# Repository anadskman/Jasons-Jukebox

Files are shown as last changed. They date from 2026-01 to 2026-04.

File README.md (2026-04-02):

# Jasons-Jukebox

jasonsjukebox

A minecraft style jukebox, uses a RFID reader and card(the disk). Then plays music through a DFPlayer. This is powered by a esp32-c3

### My Experience

I had a great time making this project, the easiest part in my opinion was designing the case. I added wood texures to the squares to make the pattern easier to see. The hardest part was the Code as im still new to it but I believe everything is correct.

### BOM
- 1x ESP32-C3 Super Mini
- 1x MFRC522 RFID reader
- 1x DFPlayer Mini
- 1x Speaker
- 1x Micro-SD card
- 1x Slide switch SPDT
- 2x M4 screws
- 2x M4 washers

- 1x Jasons-jukebox-code.ino
- 1x top-case.stl
- 4x side-case.stl
- 1x card-holder.stl

Schematic            |  PCB         |   Case
:-------------------------:|:-------------------------:|:-------------------------:|
 |  | 

# My Process
# 12/28/2025 - Made the schematic, footprints  

_Time spent: 2.0h_  

**I started by** adding everything into the schematic. I added an **esp32-c3-DevkitM-1**, **Slider Switch**, and imported a **Speaker**.
**What ended up taking so long** was trying to find symbols for the **MFRC522** and **DFPlayer**.
When I realized KiCad didn't have the symbols I tried to make them myself but then I realized there's probably some already made, so I downloaded them from SnapMagic.
**Afterwards** I wired everything together and assigned their footprints.



# 12/29/2025 3 PM - Made The PCB  

_Time spent: 0.8h_  

I **Routed** and **placed** the Components for the **PCB**.
This took a little **less than an hour** to do, I tried to keep in mind how I'd want it to sit into the jukebox so the RFID can still be used.
I'm thinking ill have it in the **top** and can be **taken out** if needed.


# 12/29/2025 6 PM - Remade Schematic and PCB, Started CAD Design  

_Time spent: 2.3h_  

I started with the **CAD Design** but Realised it would be better to use an **ESP-c3 super mini** board instead, so I remade the **schematic** wiring and the **PCB**. I also added **two m4 holes** on the PCB for **Mounting**.
Inside **Fusion 360** I uploaded the components and placed them on the PCB.
After that I Worked on the design for the **Case**.
I made the top with two slots on top, the bigger one for the PCB and the smaller one to actually insert the **RFID Card**.
Lastly I Made the side with **16x16 squares 6.563mm**. The outer squares i extruded **3mm**, then the pattern **2mm** and the rest **1mm**.
I added a **wood texture** to the design to make it easier to see.






# 1/1/2026 - Finished Case and Code  

_Time spent: 1.0h_  

I **finished** making the case and added a plate to hold the **RFID card**.
Afterwards I made the **Arduino code**, this took a good bit to do but wasn't horrible.
Then I uploaded everything to **GitHub**.



# 1/3/2026 - Made BOM  

_Time spent: 0.9h_  

I found all the parts in **aliexpress**, the **DFPlayer**, **RFID Set**, **Speakers**, **SD Card**, and **esp board**.
Then I made the **BOM** inside **google sheets** and added the **urls** and **total cost**.
I left out the **discounts** incase they **expire** before I order.





# 1/26/2026 - Parts Arrived(kinda)  

_Time spent: 2.6h_  

Everything execpt the pcb arrived so i tried connecting to a bread board a testing it.
I started by just testing the dfplayer and esp but it wasnt working so i spent a long ah time testing and i found out it was a dud so now i have to order a new one, probably off amazon so itll work.

the next day I tested the rfid and it wasnt gettting powered, i just had to solder headers on.




# 2/13/2026 - Soldered the PCB together  

_Time spent: 2.0h_  

I started by testing all the components once the new dfplayer arrived and it all worked well.
I think the other dfplayer either was a fault or I did something wrong, who knows.
After that I soldered the pcb together, turns out it was slightly wrong so i had to solder the vcc on for the rfid to 3v with wire and break the trace. I also had to break the trace and add the resistor for the RX pin on the dfplayer.


# 2/15/2026 - Fixed Cad  

_Time spent: 2.0h_  

I made the sides of the jukebox smaller to cut down on print time.


Unfortunally i had to add conners to make the case a little bigger as i already printed the sides by the time i realised.


I made the top look alot nicer and im taking advantage of the bottom being open by mounting the pcb from there with a small piece.  

# 2/20/2026 - Made the Case  

_Time spent: 2.5h_  


I started my 3d printing the case but I deciced to make the case smaller to cut down on print times
I printed 2 of the sides at 1 time and then the other two after.
while they were printing i was working on making the pcb fit as sizing down messed that up which i realised a little late but i redesigned the top to make it look more like the minecraft version and it looks a lot better.
I also noticed the pcb wouldnt fit so i had to add little conners to glue on.
The next day i painted everything, this was pretty slow but i think it was worth it.


_**I finished painting everything about an hour later.**_



After everything was painted, the top plate and sides, i glued it all together execpt the little mount i made for the pcb, ill have to line that up but i may change the design.



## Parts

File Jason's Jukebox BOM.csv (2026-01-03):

Item | Description | Qty | Price(€) | Url | Total
1pcs MFRC-522 | RFID Reader and Card | 1 | 1.68 | https://www.aliexpress.com/item/32502259949.html | 1.68
Mini Speakers 4ohm 3W | Speaker | 2 | 1.51 | https://www.aliexpress.com/item/1005010215641447.html | 1.51
DFPlayer Mini | DFPlayer | 1 | 0.89 | https://www.aliexpress.com/item/1005008710314390.html | 0.89
SD Card 2TB | SD Card | 1 | 4.44 | https://www.aliexpress.com/item/1005009550590600.html | 4.44
ESP32-C3 Supermini | Dev Board | 1 | 2.83 | https://www.aliexpress.com/item/1005009495310442.html | 2.83
 |  |  |  | Shipping | 9.15
 |  |  |  | Total | 20.5

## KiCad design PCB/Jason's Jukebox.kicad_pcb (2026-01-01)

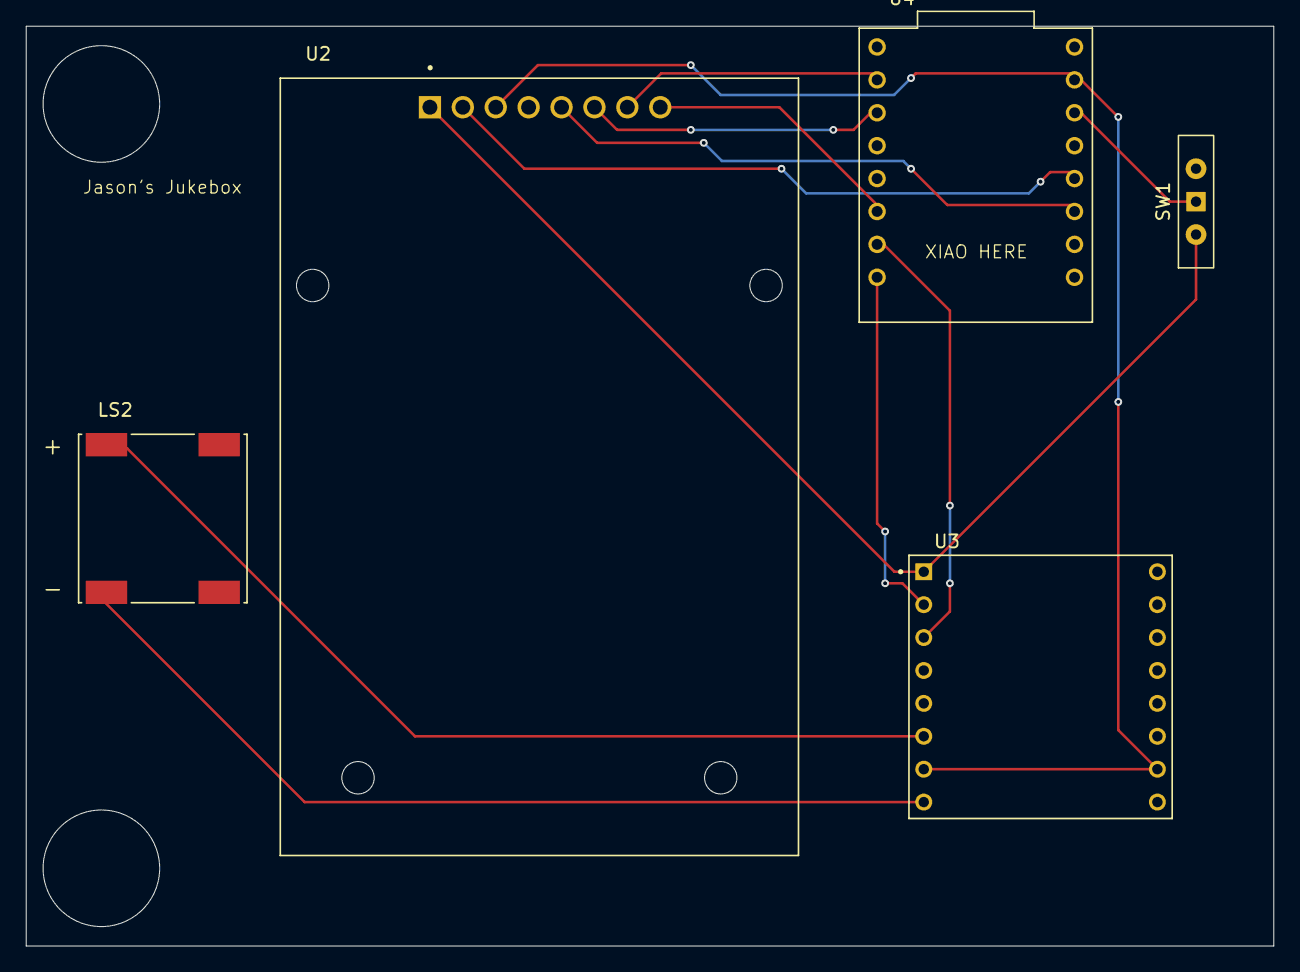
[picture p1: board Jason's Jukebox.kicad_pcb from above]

Board: 2 copper layers, 96.3 x 71.0 mm, 5 parts (0 on the bottom side), 12 nets.

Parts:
LS2: Speaker; SPKR_KAAG13008-07C
SW1: Slider Switch; SW_Slide-03_Wuerth-WS-SLTV_10x2.5x6.4_P2.54mm
U2: RFID; MODULE_CEG006900
U3: DFPlayer; MODULE_DFR0299
U4: ESP32-C3_SUPERMINI_TH; MODULE_ESP32-C3_SUPERMINI_TH

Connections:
+3.3V: SW1.1 (B), U4.3.3 (3V3)
GND: U2.3 (GND), U3.7 (GND), U3.10 (GND), U4.G (GND)
unnamed: SW1.2 (C), U2.1 (VCC), U3.1 (VCC)
unnamed: U2.5 (MISO/SCL/TX), U4.2 (GPIO2)
unnamed: U2.6 (MOSI), U4.7 (GPIO7)
unnamed: U2.2 (RST), U4.3 (GPIO3)
unnamed: U2.7 (SCK), U4.6 (GPIO6)
unnamed: U2.8 (SS/SDA/RX), U4.10 (GPIO10)
unnamed: U3.2 (RX), U4.21 (GPIO21)
unnamed: LS2.P, U3.6 (SPK1)
unnamed: LS2.N, U3.8 (SPK2)
unnamed: U3.3 (TX), U4.20 (GPIO20)

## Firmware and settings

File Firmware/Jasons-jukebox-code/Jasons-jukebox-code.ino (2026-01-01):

#define SS_PIN   10
#define RST_PIN  3

#define SPI_SCK  6
#define SPI_MOSI 7
#define SPI_MISO 2

#define DF_RX 20
#define DF_TX 21

#include <SPI.h>
#include <MFRC522.h>
#include <DFRobotDFPlayerMini.h>

MFRC522 rfid(SS_PIN, RST_PIN);
DFRobotDFPlayerMini dfplayer;

HardwareSerial dfSerial(1);

// Replace this UID
byte allowedUID[4] = {0xDE, 0xAD, 0xBE, 0xEF};

bool playing = false;

void setup() {
  Serial.begin(115200);

  SPI.begin(SPI_SCK, SPI_MISO, SPI_MOSI, SS_PIN);

  rfid.PCD_Init();

  dfSerial.begin(9600, SERIAL_8N1, DF_RX, DF_TX);

  if (!dfplayer.begin(dfSerial)) {
    Serial.println("DFPlayer not found");
    while (true);
  }

  dfplayer.volume(20); // 0–30
  dfplayer.stop();

  Serial.println("Ready. Scan RFID.");
}

void loop() {
  if (!rfid.PICC_IsNewCardPresent()) return;
  if (!rfid.PICC_ReadCardSerial()) return;

  if (checkUID()) {
    Serial.println("Card accepted");

    if (!playing) {
      dfplayer.play(1);
      playing = true;
    } else {
      dfplayer.stop();
      playing = false;
    }
  } else {
    Serial.println("Unknown card");
  }

  rfid.PICC_HaltA();
  rfid.PCD_StopCrypto1();
  delay(1000);
}

bool checkUID() {
  if (rfid.uid.size != 4) return false;

  for (byte i = 0; i < 4; i++) {
    if (rfid.uid.uidByte[i] != allowedUID[i]) {
      return false;
    }
  }
  return true;
}
